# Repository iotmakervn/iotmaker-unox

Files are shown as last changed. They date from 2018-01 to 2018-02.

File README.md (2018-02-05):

# IoT Maker - UnoX

## Features

IoTMaker UnoX:  
- Power input 6.5V to 12VDC - recomment 9V (1A/5V output) and 5V USB
- Additional Button, LED, header for external module : variable, servo, common sensor.
- Open hardware with CC-BY-SA license
- Design with KiCad

## Hardware

### Schematics

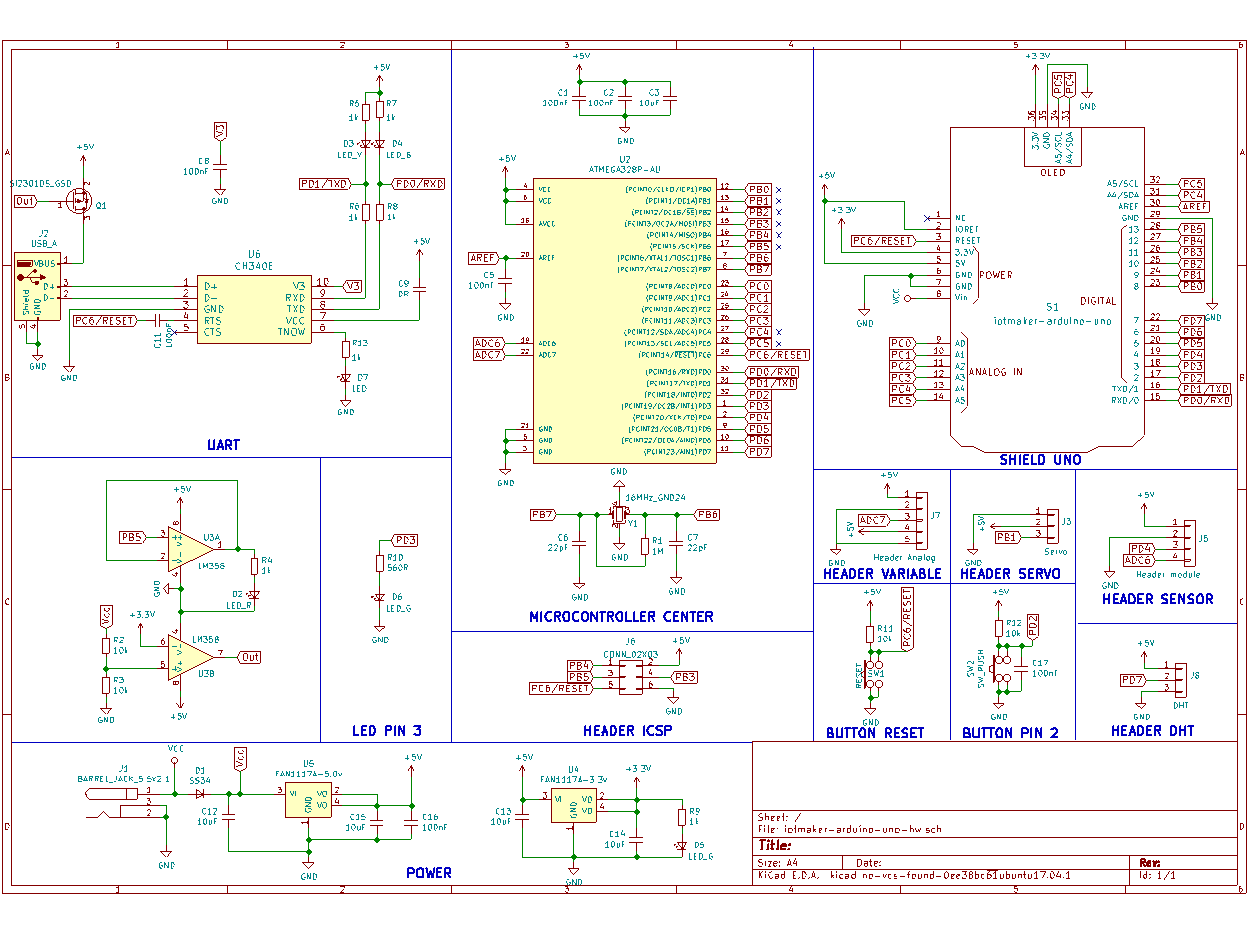
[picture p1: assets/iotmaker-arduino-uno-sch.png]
IoTMaker Arduino Uno Schematic


### PCB Layout

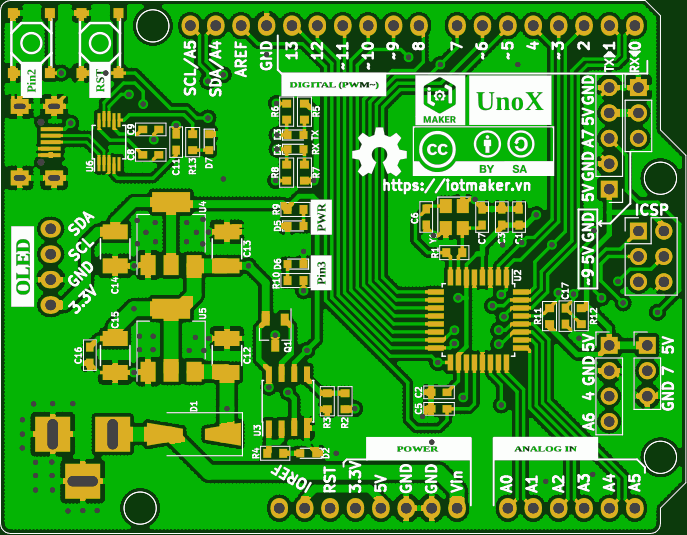
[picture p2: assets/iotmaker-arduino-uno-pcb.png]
IoTMaker Arduino Uno PCB


### 3D

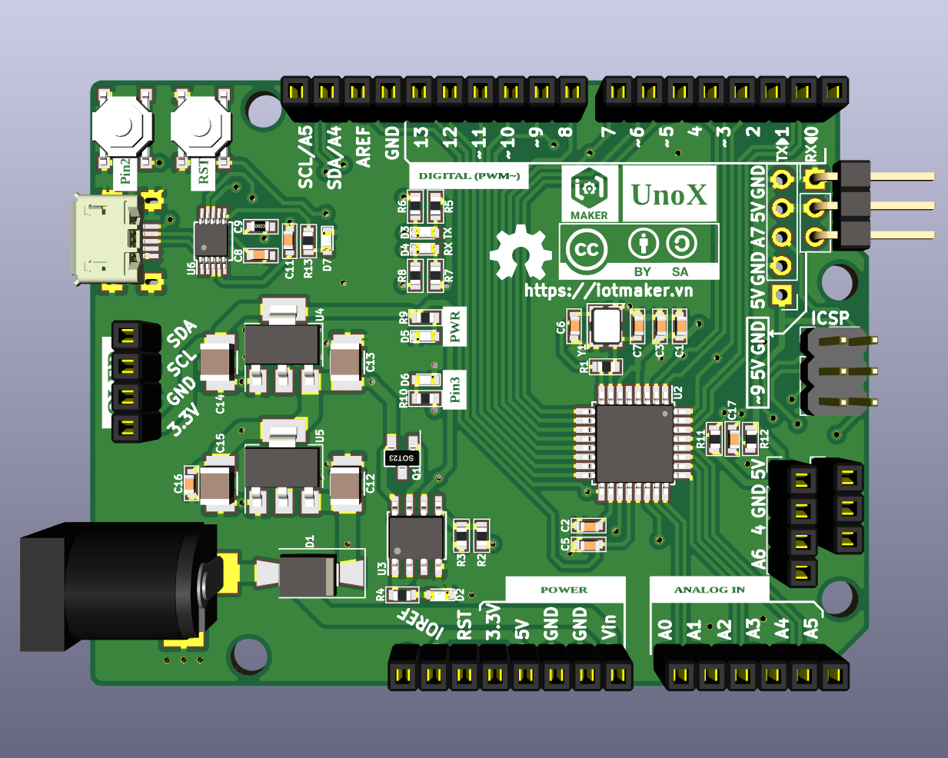
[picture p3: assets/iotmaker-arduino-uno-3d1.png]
IoTMaker Arduino Uno 3D


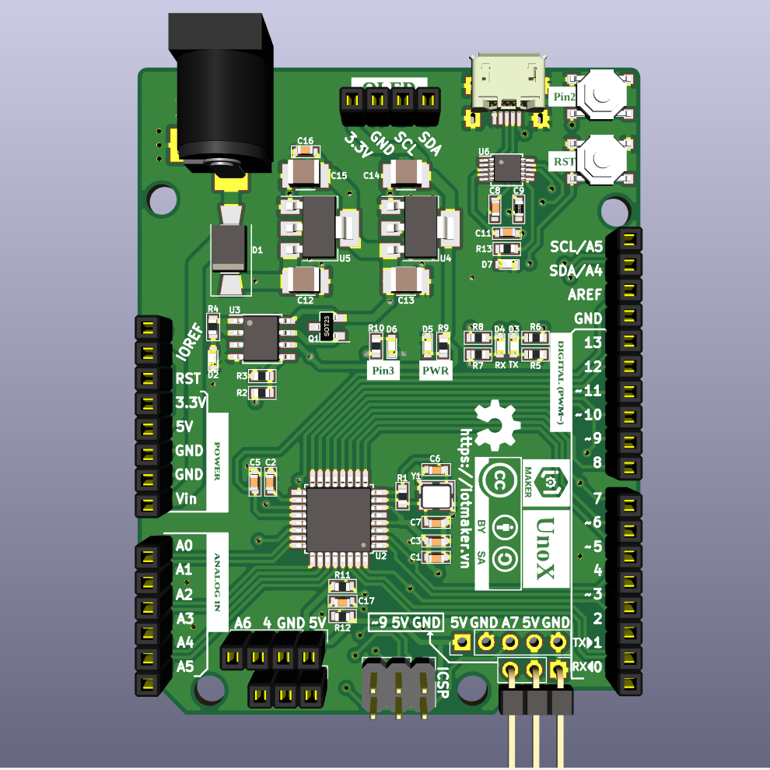
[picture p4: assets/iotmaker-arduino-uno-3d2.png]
IoTMaker Arduino Uno 3D


### Pinout 

### Gerber

[Download gerber sigle](./assets/iotmaker-arduino-uno-68,58x53,34mm.zip)

[Download gerber panel](./assets/panel-iotmaker-arduino-uno.zip)

### Remark

This project was in development phase - we will remove this remark after release

# License



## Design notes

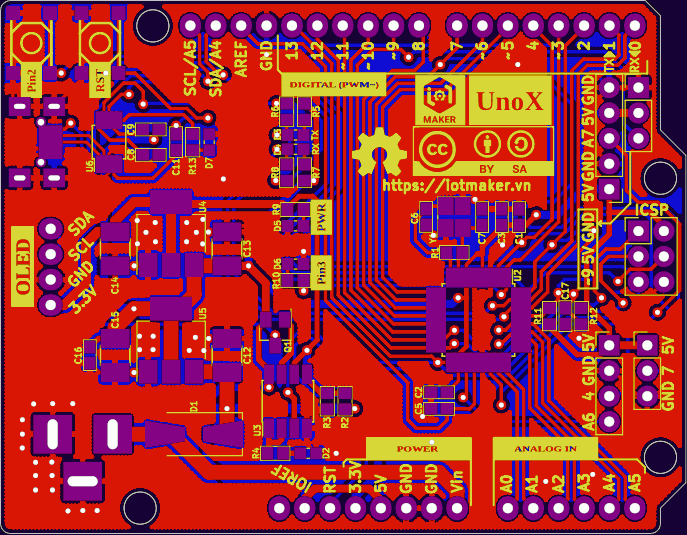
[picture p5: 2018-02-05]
assets/iotmaker-arduino-uno-pcb2.png

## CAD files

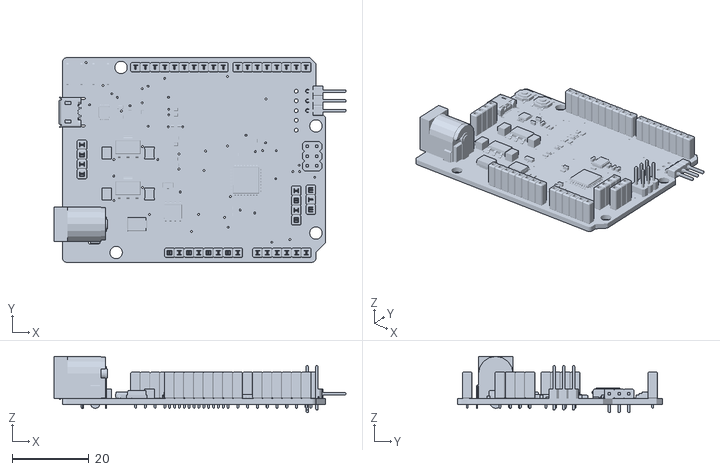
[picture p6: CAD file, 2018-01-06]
assets/iotmaker-arduino-uno-3d.stl
76.1 x 53.3 x 14.7

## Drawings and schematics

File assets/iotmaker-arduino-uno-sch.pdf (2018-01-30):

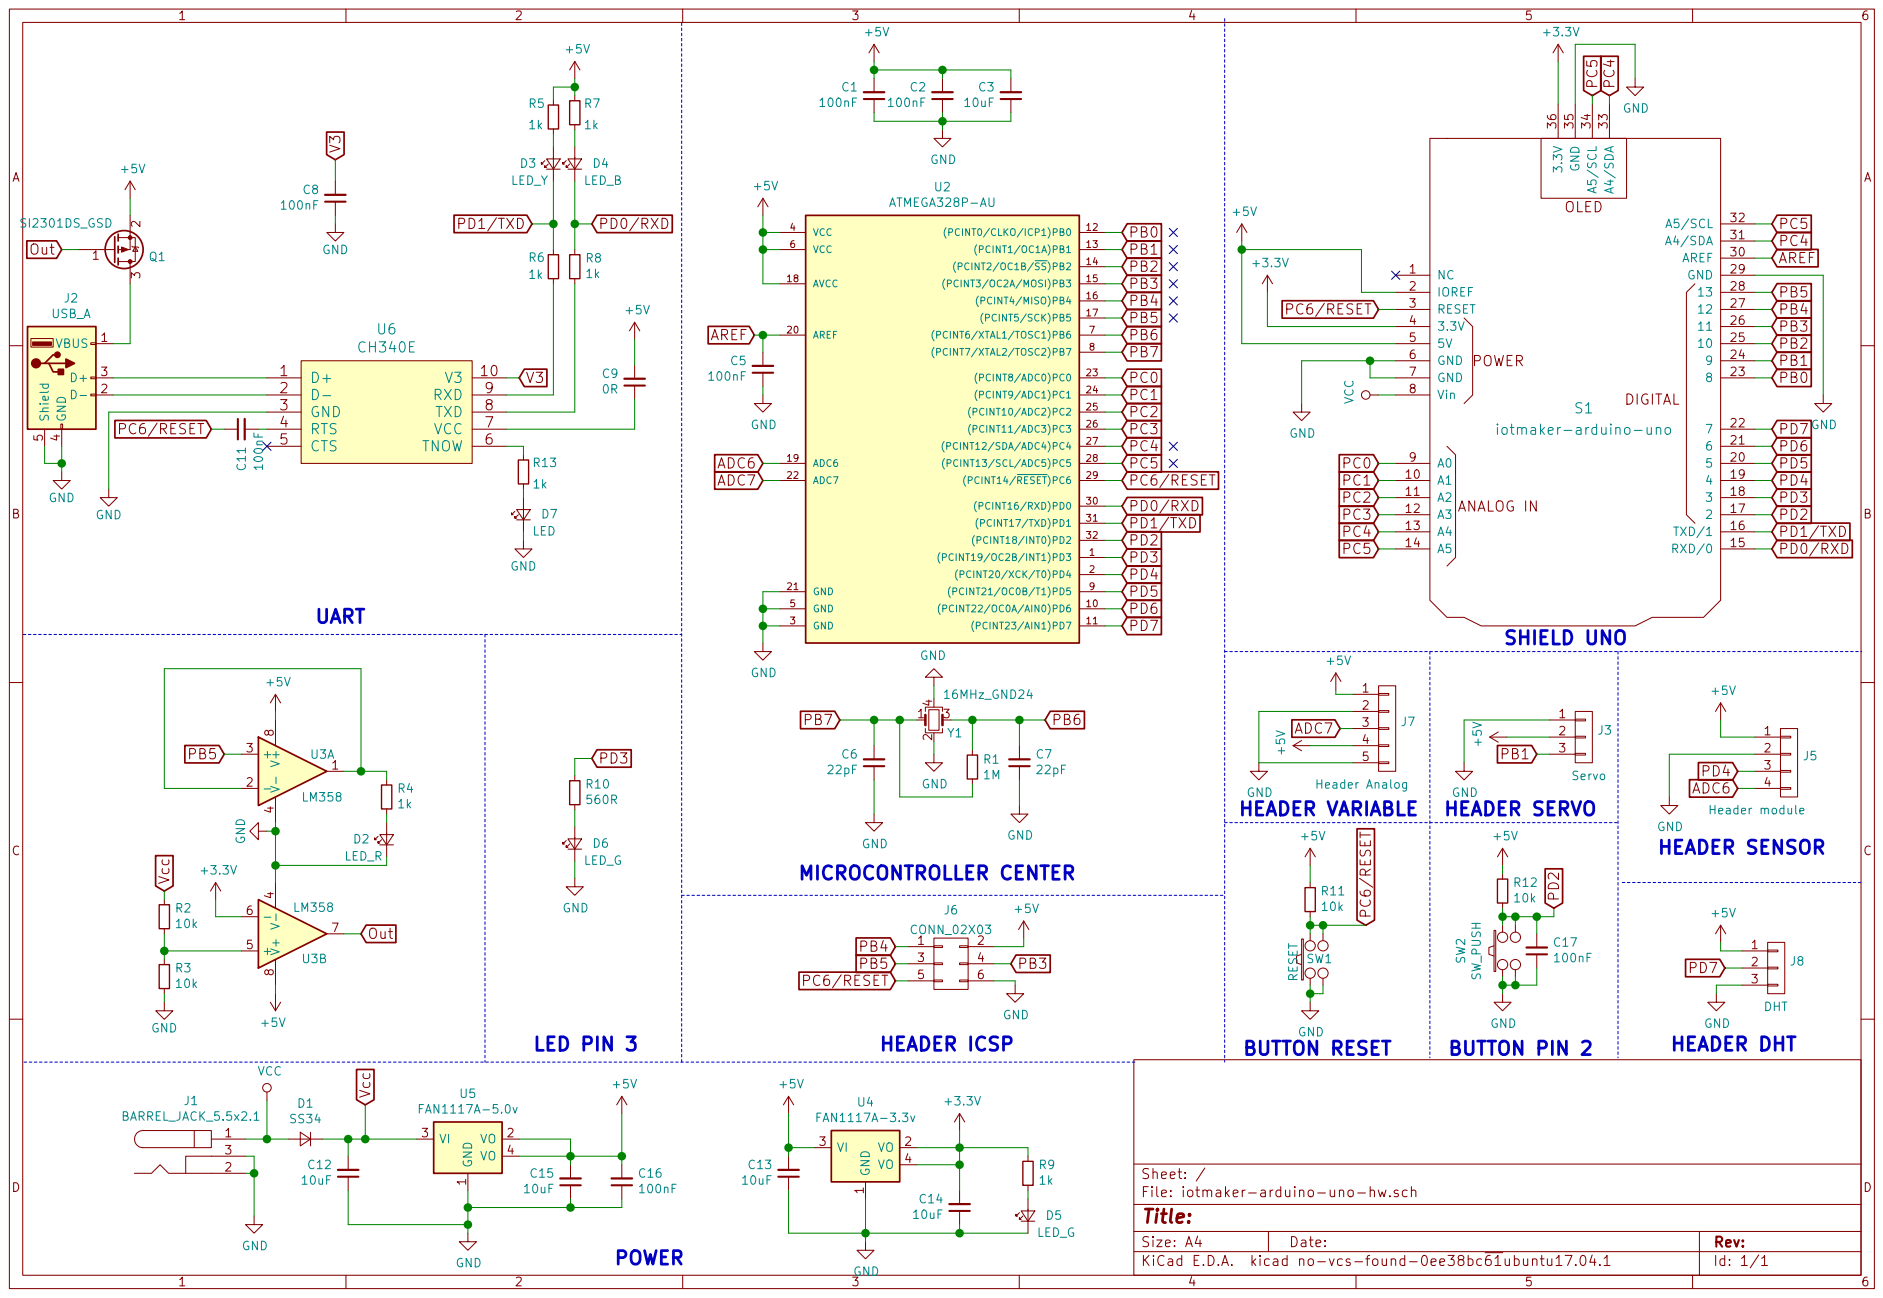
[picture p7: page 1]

Id: 1/1 Title: File: iotmaker-arduino-uno-hw.sch Sheet: /

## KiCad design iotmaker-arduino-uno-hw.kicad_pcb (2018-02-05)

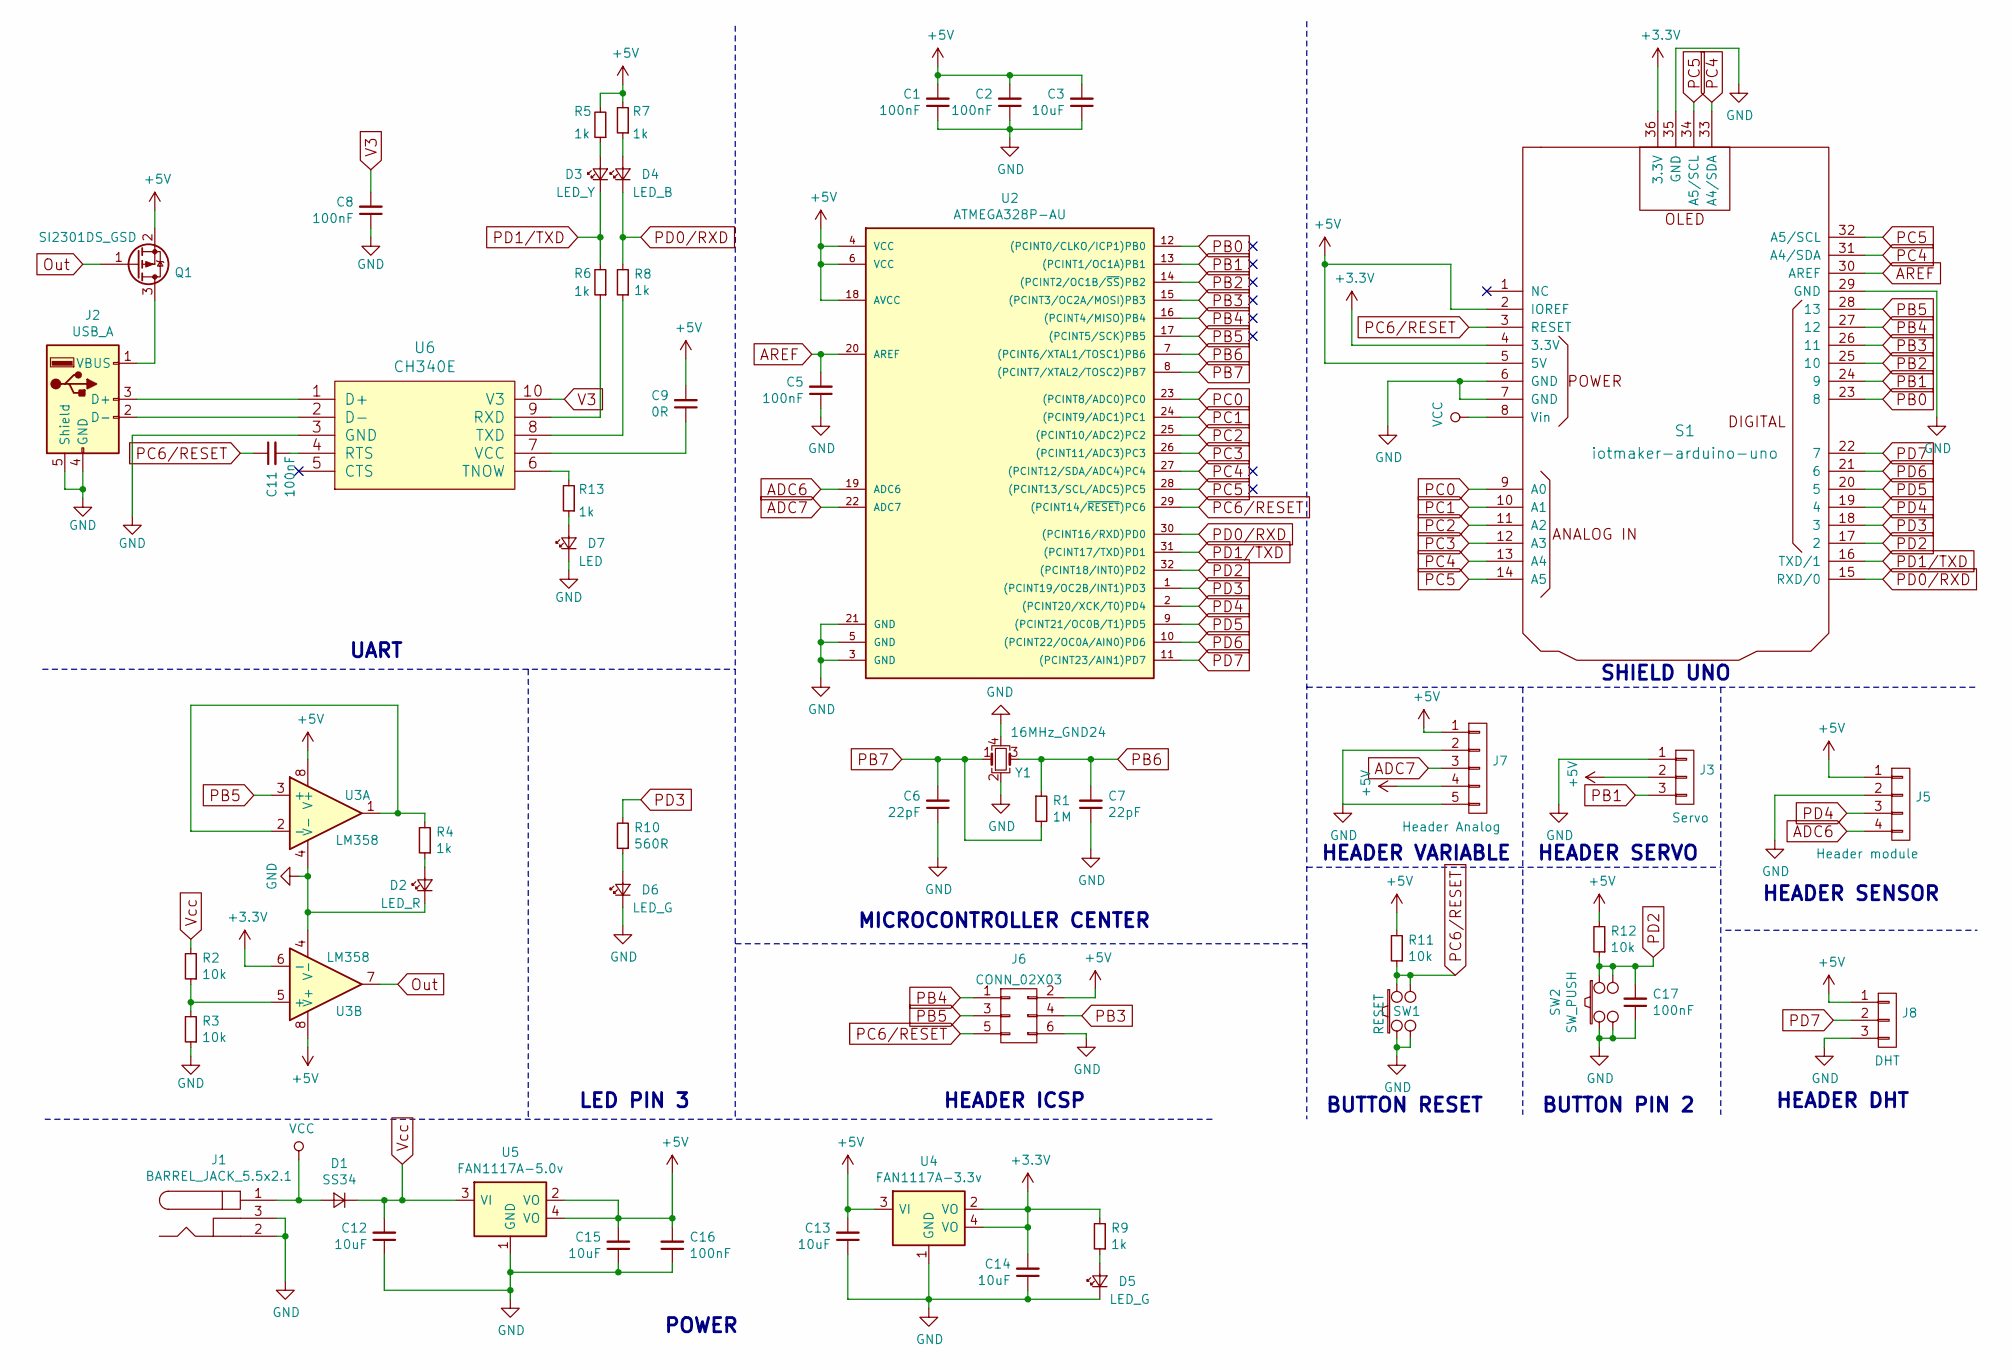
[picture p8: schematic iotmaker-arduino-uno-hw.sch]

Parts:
C1, C2, C5, C8, C11, C16, C17: 100nF; C_0603
C3: 10uF; C_0603
C6, C7: 22pF; C_0603
C9: 0R; C_0603
C12, C13, C14, C15: 10uF; C_1210
D1: SS34; D_SMA-SMB_Universal_Handsoldering
D2: LED_R; LED_0603
D3: LED_Y; LED_0603
D4: LED_B; LED_0603
D5, D6: LED_G; LED_0603
D7: LED; LED_0603
J1: BARREL_JACK_5.5x2.1; BARREL_JACK
J2: USB_A; MicroUSB-B
J3: Servo; Pin_Header_Straight_1x03_Pitch2.54mm
J5: Header module; Pin_Header_Straight_1x04_Pitch2.54mm
J6: CONN_02X03; Pin_Header_Straight_2x03_Pitch2.54mm
J7: Header Analog; Pin_Header_Straight_1x05_Pitch2.54mm
J8: DHT; Pin_Header_Straight_1x03_Pitch2.54mm
Q1: SI2301DS_GSD; SOT-23_standar
R1: 1M; R_0603
R2, R3, R11, R12: 10k; R_0603
R4, R5, R6, R7, R8, R9, R13: 1k; R_0603
R10: 560R; R_0603
S1: iotmaker-arduino-uno
SW1: RESET; smd_push2
SW2: SW_PUSH; smd_push2
U2: ATMEGA328P-AU; TQFP-32_7x7mm_Pitch0.8mm
U3: LM358; SOIC-8_3.9x4.9mm_Pitch1.27mm
U4: FAN1117A-3.3v; SOT-223
U5: FAN1117A-5.0v; SOT-223
U6: CH340E; MSOP-10_3x3mm_Pitch0.5mm
Y1: 16MHz_GND24; Crystal_SMD_3225-4pin_3.2x2.5mm

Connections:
+3V3: C14.2, R9.2, S1.4 (3.3V), S1.36 (3.3V), U3.6 (-), U4.2 (VO), U4.4 (VO)
+5V: C1.2, C2.2, C3.2, C9.2, C13.2, C15.2, C16.2, J3.2, J5.1, J6.2, J7.1, J7.4, J8.1, Q1.2 (S), R5.2, R7.2, R11.2, R12.2, S1.2 (IOREF), S1.5 (5V), U2.4 (VCC), U2.6 (VCC), U2.18 (AVCC), U3.8 (V+), U4.3 (VI), U5.2 (VO), U5.4 (VO)
ADC6: J5.4, U2.19 (ADC6)
ADC7: J7.3, U2.22 (ADC7)
AREF: C5.2, S1.30 (AREF), U2.20 (AREF)
GND: C1.1, C2.1, C3.1, C5.1, C6.1, C7.1, C8.1, C12.1, C13.1, C14.1, C15.1, C16.1, C17.1, D2.1 (K), D5.1 (K), D6.1 (K), D7.1 (K), J1.2, J1.3, J2.4 (GND), J2.5 (Shield), J3.1, J5.2, J6.6, J7.2, J7.5, J8.3, R3.1, S1.6 (GND), S1.7 (GND), S1.29 (GND), S1.35 (GND), SW1.1, SW1.2, SW2.3, SW2.4, U2.3 (GND), U2.5 (GND), U2.21 (GND), U3.4 (V-), U4.1 (GND), U5.1 (GND), U6.3 (GND), Y1.2, Y1.4
unnamed: C9.1, U6.7 (VCC)
unnamed: C11.2, U6.4 (RTS)
unnamed: D2.2 (A), R4.1
unnamed: D3.2 (A), R5.1
unnamed: D4.2 (A), R7.1
unnamed: D5.2 (A), R9.1
unnamed: D6.2 (A), R10.1
unnamed: D7.2 (A), R13.1
unnamed: J2.1 (VBUS), Q1.3 (D)
unnamed: J2.2 (D-), U6.2 (D-)
unnamed: J2.3 (D+), U6.1 (D+)
unnamed: R2.1, R3.2, U3.5 (+)
unnamed: R4.2, U3.1, U3.2 (-)
unnamed: R6.1, U6.9 (RXD)
unnamed: R8.1, U6.8 (TXD)
unnamed: R13.2, U6.6 (TNOW)
Out: Q1.1 (G), U3.7
PB0: S1.23 (8), U2.12 ((PCINT0/CLKO/ICP1)PB0)
PB1: J3.3, S1.24 (9), U2.13 ((PCINT1/OC1A)PB1)
PB2: S1.25 (10), U2.14 ((PCINT2/OC1B/~SS~)PB2)
PB3: J6.4, S1.26 (11), U2.15 ((PCINT3/OC2A/MOSI)PB3)
PB4: J6.1, S1.27 (12), U2.16 ((PCINT4/MISO)PB4)
PB5: J6.3, S1.28 (13), U2.17 ((PCINT5/SCK)PB5), U3.3 (+)
PB6: C7.2, R1.1, U2.7 ((PCINT6/XTAL1/TOSC1)PB6), Y1.3
PB7: C6.2, R1.2, U2.8 ((PCINT7/XTAL2/TOSC2)PB7), Y1.1
PC0: S1.9 (A0), U2.23 ((PCINT8/ADC0)PC0)
PC1: S1.10 (A1), U2.24 ((PCINT9/ADC1)PC1)
PC2: S1.11 (A2), U2.25 ((PCINT10/ADC2)PC2)
PC3: S1.12 (A3), U2.26 ((PCINT11/ADC3)PC3)
PC4: S1.13 (A4), S1.31 (A4/SDA), S1.33 (A4/SDA), U2.27 ((PCINT12/SDA/ADC4)PC4)
PC5: S1.14 (A5), S1.32 (A5/SCL), S1.34 (A5/SCL), U2.28 ((PCINT13/SCL/ADC5)PC5)
PC6/RESET: C11.1, J6.5, R11.1, S1.3 (RESET), SW1.3, SW1.4, U2.29 ((PCINT14/~RESET~)PC6)
PD0/RXD: D4.1 (K), R8.2, S1.15 (RXD/0), U2.30 ((PCINT16/RXD)PD0)
PD1/TXD: D3.1 (K), R6.2, S1.16 (TXD/1), U2.31 ((PCINT17/TXD)PD1)
PD2: C17.2, R12.1, S1.17 (2), SW2.1, SW2.2, U2.32 ((PCINT18/INT0)PD2)
PD3: R10.2, S1.18 (3), U2.1 ((PCINT19/OC2B/INT1)PD3)
PD4: J5.3, S1.19 (4), U2.2 ((PCINT20/XCK/T0)PD4)
PD5: S1.20 (5), U2.9 ((PCINT21/OC0B/T1)PD5)
PD6: S1.21 (6), U2.10 ((PCINT22/OC0A/AIN0)PD6)
PD7: J8.2, S1.22 (7), U2.11 ((PCINT23/AIN1)PD7)
V3: C8.2, U6.10 (V3)
VCC: D1.2 (A), J1.1, S1.8 (Vin)
Vcc: C12.2, D1.1 (K), R2.2, U5.3 (VI)

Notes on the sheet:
BUTTON RESET
BUTTON PIN 2
HEADER DHT
HEADER SENSOR
HEADER SERVO
HEADER VARIABLE
SHIELD UNO
HEADER ICSP
MICROCONTROLLER CENTER
LED PIN 3
UART
POWER

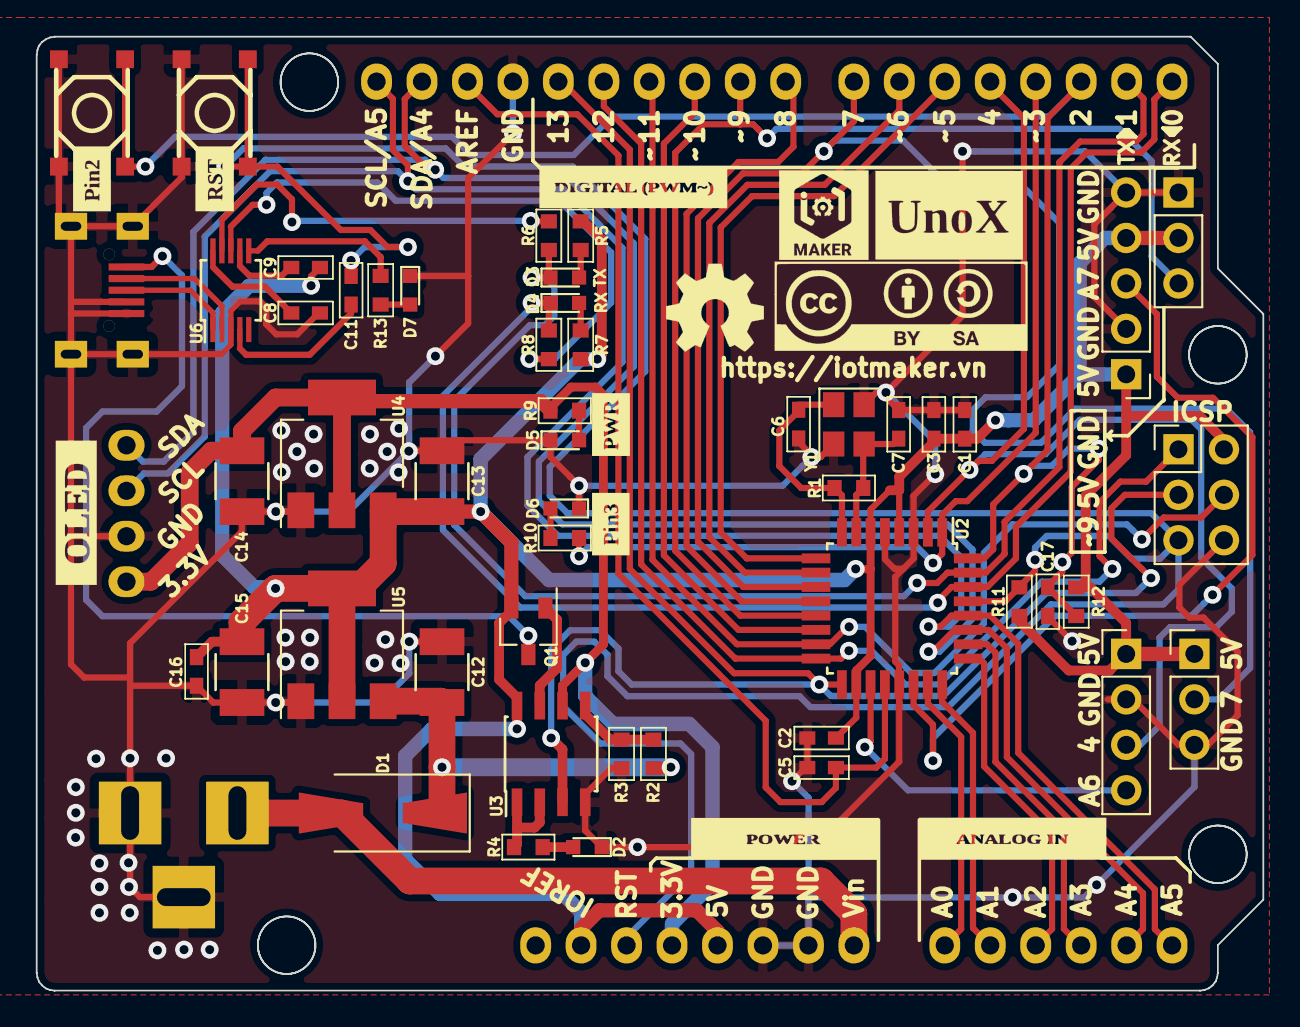
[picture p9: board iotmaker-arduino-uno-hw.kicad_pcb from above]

Board: 2 copper layers, 68.5 x 53.3 mm, 52 parts (0 on the bottom side), 49 nets.

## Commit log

2018-01-02 Final basic schematic & pcb
    [iotmaker-arduino-uno-hw.kicad_pcb, iotmaker-arduino-uno-hw.sch]
2018-01-06 basic completed pcb
    [iotmaker-arduino-uno-hw.kicad_pcb, iotmaker-arduino-uno-hw.sch]
2018-01-06 cchange CH340G to CH340E & update information board, gerber file
    [iotmaker-arduino-uno-3d.stl, iotmaker-arduino-uno-hw.kicad_pcb, iotmaker-arduino-uno-hw.sch]
2018-01-30 drop c4
    [iotmaker-arduino-uno-hw.sch]
2018-01-30 remap symbol with new version kicad
    [iotmaker-arduino-uno-hw-2018-01-29-12-03-56.sch, iotmaker-arduino-uno-hw-2018-01-30-10-38-36.sch, iotmaker-arduino-uno-hw.kicad_pcb]
2018-01-30 change button pin8 to pin2 and header pin2 to pin7
    [iotmaker-arduino-uno-hw.kicad_pcb, iotmaker-arduino-uno-hw.sch]
2018-01-30 final modify board and update assets
    [iotmaker-arduino-uno-hw-2018-01-29-12-03-56.sch, iotmaker-arduino-uno-hw-2018-01-30-10-38-36.sch]
2018-02-02 add gerber 4 panel
2018-02-02 add link download gerber 4 panel
2018-02-05 update gerber pcb & gerber 4 panel
    [iotmaker-arduino-uno-hw.kicad_pcb]

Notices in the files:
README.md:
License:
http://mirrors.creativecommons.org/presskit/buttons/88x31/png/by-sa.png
